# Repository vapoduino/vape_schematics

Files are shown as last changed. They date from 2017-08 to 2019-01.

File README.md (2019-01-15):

# Open Source Vape schematics
This is the repository for the schematics of the open source vape.

It is based on Arduino and uses a MAX31865 for reading the temperature of a PT100 sensor.
For charging the LiPo batteries, a TP4056 is used.
The heat emitted by the heating wire is controled using a PH2925U mosfet.

There still are a lot of errors in this schematics, but you will get the general idea...

## Firmware
The Firmware can be found at [vapoduino/vape_firmware_arduino](https://github.com/vapoduino/vape_firmware_arduino)

## Model 
The model can be found at [vapoduino/vape_model](https://github.com/vapoduino/vape_model)

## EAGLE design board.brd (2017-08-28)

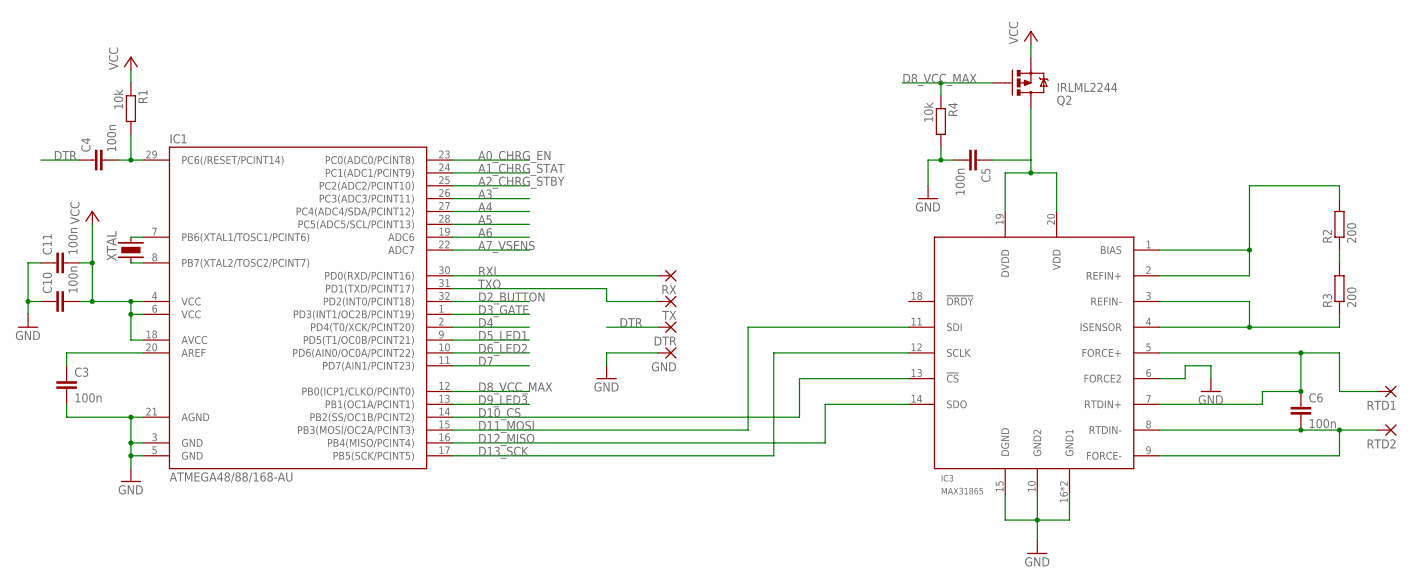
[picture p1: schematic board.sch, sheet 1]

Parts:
C3, C4, C5, C6, C10, C11: 100n; C0603
DTR: SMD2; SMD1,27-2,54
GND: SMD2; SMD1,27-2,54
IC1: ATMEGA48/88/168-AU; TQFP32-08
IC3: MAX31865; TQFN20-5X5
Q2: IRLML2244; SOT23-3
R1, R4: 10k; R0603
R2, R3: 200; R0603
RTD1, RTD2: SMD2; SMD1,27-2,54
RX: SMD2; SMD1,27-2,54
TX: SMD2; SMD1,27-2,54
XTAL: XTAL-HCS10; CS10

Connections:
A0_CHRG_EN: IC1.23 (PC0(ADC0/PCINT8)); also elsewhere on the board
A1_CHRG_STAT: IC1.24 (PC1(ADC1/PCINT9)); also elsewhere on the board
A2_CHRG_STBY: IC1.25 (PC2(ADC2/PCINT10)); also elsewhere on the board
A3: IC1.26 (PC3(ADC3/PCINT11))
A4: IC1.27 (PC4(ADC4/SDA/PCINT12))
A5: IC1.28 (PC5(ADC5/SCL/PCINT13))
A6: IC1.19 (ADC6)
A7_VSENS: IC1.22 (ADC7); also elsewhere on the board
AREF: C3.1, IC1.20 (AREF)
D2_BUTTON: IC1.32 (PD2(INT0/PCINT18)); also elsewhere on the board
D3_GATE: IC1.1 (PD3(INT1/OC2B/PCINT19)); also elsewhere on the board
D4: IC1.2 (PD4(T0/XCK/PCINT20))
D5_LED1: IC1.9 (PD5(T1/OC0B/PCINT21)); also elsewhere on the board
D6_LED2: IC1.10 (PD6(AIN0/OC0A/PCINT22)); also elsewhere on the board
D7: IC1.11 (PD7(AIN1/PCINT23))
D8_VCC_MAX: IC1.12 (PB0(ICP1/CLKO/PCINT0)), Q2.1 (G), R4.1
D9_LED3: IC1.13 (PB1(OC1A/PCINT1)); also elsewhere on the board
D10_CS: IC1.14 (PB2(SS/OC1B/PCINT2)), IC3.13 (!CS)
D11_MOSI: IC1.15 (PB3(MOSI/OC2A/PCINT3)), IC3.11 (SDI)
D12_MISO: IC1.16 (PB4(MISO/PCINT4)), IC3.14 (SDO)
D13_SCK: IC1.17 (PB5(SCK/PCINT5)), IC3.12 (SCLK)
DTR: C4.1, DTR.1
GND: C3.2, C5.2, C10.1, C11.1, GND.1, IC1.3 (GND), IC1.5 (GND), IC1.21 (AGND), IC3.6 (FORCE2), IC3.10 (GND2), IC3.15 (DGND), IC3.16 (GND1), IC3.EXP (GND1), R4.2; also elsewhere on the board
unnamed: R2.1, R3.2
RST: C4.2, IC1.29 (PC6(/RESET/PCINT14)), R1.2
RXI: IC1.30 (PD0(RXD/PCINT16)), RX.1
TEMP_IN+: C6.1, IC3.5 (FORCE+), IC3.7 (RTDIN+), RTD1.1
TEMP_IN-: C6.2, IC3.8 (RTDIN-), IC3.9 (FORCE-), RTD2.1
TEMP_REF+: IC3.1 (BIAS), IC3.2 (REFIN+), R2.2
TEMP_REF-: IC3.3 (REFIN-), IC3.4 (ISENSOR), R3.1
TXO: IC1.31 (PD1(TXD/PCINT17)), TX.1
VCC: C10.2, C11.2, IC1.4 (VCC), IC1.6 (VCC), IC1.18 (AVCC), Q2.2 (S), R1.1; also elsewhere on the board
VCC_MAX: C5.1, IC3.19 (DVDD), IC3.20 (VDD), Q2.3 (D)
XTAL1: IC1.7 (PB6(XTAL1/TOSC1/PCINT6)), XTAL.R (P2)
XTAL2: IC1.8 (PB7(XTAL2/TOSC2/PCINT7)), XTAL.L (P1)

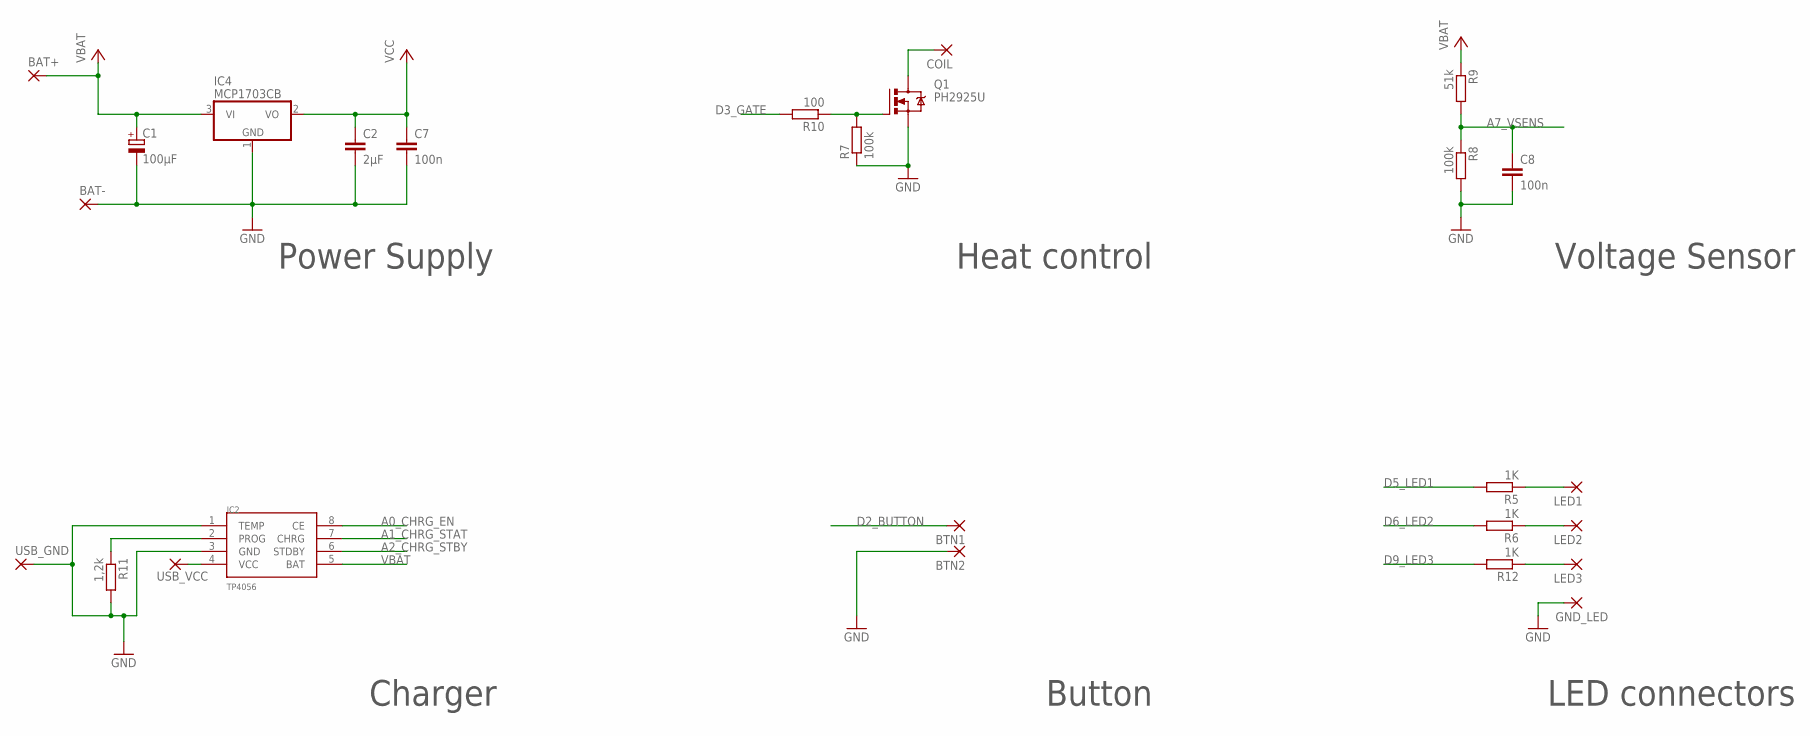
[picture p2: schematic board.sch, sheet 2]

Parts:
BAT+: SMD2; SMD1,27-2,54
BAT-: WIREPAD4,16O1,6; 4,16O1,6
BTN1, BTN2: SMD2; SMD1,27-2,54
C1: 100µF; CT7343
C2: 2µF; C1206
C7, C8: 100n; C0603
COIL: WIREPAD4,16O1,6; 4,16O1,6
GND_LED: SMD2; SMD1,27-2,54
IC2: TP4056; SOP-8
IC4: MCP1703CB; SOT23
LED1, LED2, LED3: SMD2; SMD1,27-2,54
Q1: PH2925U; SOT-669
R5, R6, R12: 1K; R0603
R7, R8: 100k; R0603
R9: 51k; R0603
R10: 100; R0603
R11: 1,2k; R0603
USB_GND: SMD2; SMD1,27-2,54
USB_VCC: SMD2; SMD1,27-2,54

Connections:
A0_CHRG_EN: IC2.8 (CE); also elsewhere on the board
A1_CHRG_STAT: IC2.7 (CHRG); also elsewhere on the board
A2_CHRG_STBY: IC2.6 (STDBY); also elsewhere on the board
A7_VSENS: C8.1, R8.1, R9.2; also elsewhere on the board
COIL: COIL.1, Q1.5 (D)
D2_BUTTON: BTN1.1; also elsewhere on the board
D3_GATE: R10.2; also elsewhere on the board
D5_LED1: R5.2; also elsewhere on the board
D6_LED2: R6.2; also elsewhere on the board
D9_LED3: R12.2; also elsewhere on the board
GATE: Q1.4 (G), R7.2, R10.1
GND: BAT-.1, BTN2.1, C1.-, C2.2, C7.2, C8.2, GND_LED.1, IC2.1 (TEMP), IC2.3 (GND), IC4.1 (GND), Q1.1 (S), Q1.2 (S), Q1.3 (S), R7.1, R8.2, R11.2, USB_GND.1; also elsewhere on the board
LED1: LED1.1, R5.1
LED2: LED2.1, R6.1
LED3: LED3.1, R12.1
PROG: IC2.2 (PROG), R11.1
VBAT: BAT+.1, C1.+, IC2.5 (BAT), IC4.3 (VI), R9.1
VCC: C2.1, C7.1, IC4.2 (VO); also elsewhere on the board
VUSB: IC2.4 (VCC), USB_VCC.1

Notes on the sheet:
Power Supply
Charger
Heat control
Button
Voltage Sensor
LED connectors

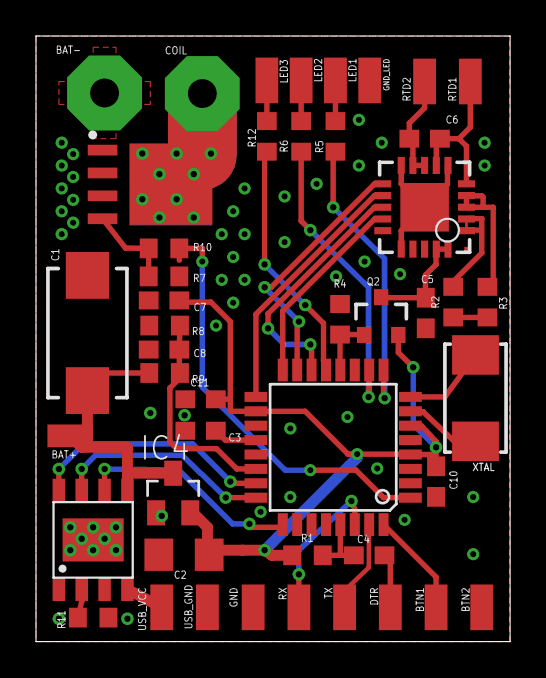
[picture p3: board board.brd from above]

Board: 2 copper layers, 26.3 x 33.6 mm, 46 parts (0 on the bottom side), 37 nets.

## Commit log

2017-03-06 splitting into separated repositories
    [board.brd, board.sch]
2017-03-06 cleanup of schematics
    [board.brd, board.sch]
2017-06-17 using smaller resistors for voltage sensor
    [board.brd, board.sch]
2017-06-22 using new mosfets, rearangement of parts
    [board.brd, board.sch]
2017-07-26 adding 3rd LED, new regulator, shrinking board
    [board.brd, board.sch]
2017-07-26 first draft of new layout
    [board.brd]
2017-07-27 adding vias for mosfet
    [board.brd]
2017-07-27 connect leds via bottom
    [board.brd]
2017-07-27 rearanging led and spi traces, adding vias for gnd and heat, checking layout, READY for production
    [board.brd]
2017-07-27 adding tstop for charger heat transfer
    [board.brd]
2017-08-28 using MCP1703 as vreg
    [board.brd, board.sch]

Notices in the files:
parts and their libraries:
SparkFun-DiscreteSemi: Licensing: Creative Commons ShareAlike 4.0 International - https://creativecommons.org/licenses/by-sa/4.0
